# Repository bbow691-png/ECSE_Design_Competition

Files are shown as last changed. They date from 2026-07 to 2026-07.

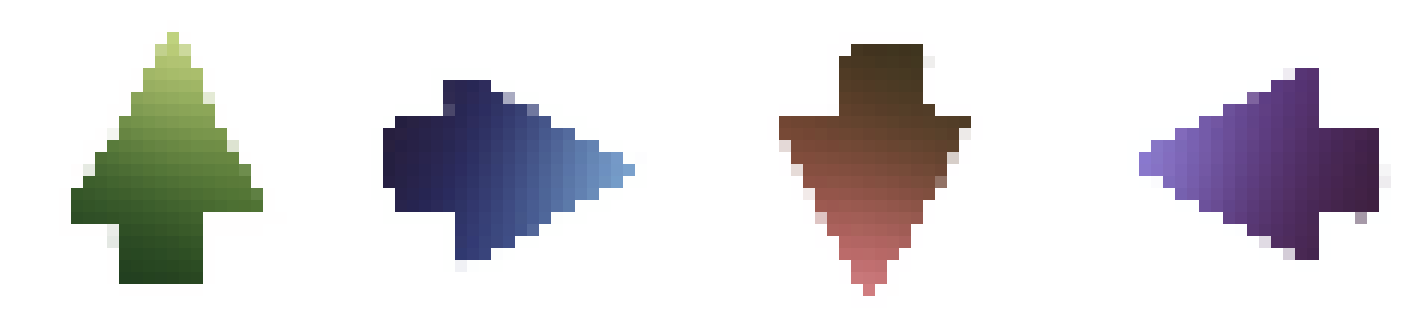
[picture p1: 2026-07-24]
godot/ecse-design/assets/images/Arrows.png

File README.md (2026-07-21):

🥁 ESP32 & Godot Rhythm Game

An open-source, hybrid rhythm game project combining custom ESP32 hardware (piezo drum pads over I2S) with a Godot 4.x game engine frontend. Hit your physical drum kit, stream analog transients via high-speed ADC sampling, and watch the notes fall in sync on your screen!

🛠️ Project Structure
├── src/                      # C++ PlatformIO firmware for the ESP32
├── godot/ecse-design/        # Godot 4.x Game Engine Project
│   ├── scenes/game_scene/    # Gameplay levels, lanes, and UI
│   ├── scripts/              # SongManager, PiezoInput, and Conductor logic
│   └── songs/                # JSON-based custom beatmaps & audio
└── run_instructions.md       # Detailed local setup guide
⚡ Part 1: Hardware Setup & ESP32 Firmware

The ESP32 uses built-in I2S ADC sampling at 20kHz to capture percussive transients from up to 4 piezo drum pads simultaneously, translating analog strikes into MIDI velocity data over USB Serial.

Prerequisites
VS Code with the PlatformIO extension installed
Flashing the ESP32
Open VS Code and use File > Open Folder to select the root folder containing your platformio.ini file.
Wait for PlatformIO to automatically download the required ESP32 toolchains and Arduino frameworks.
Plug your ESP32 into your computer via USB.
Click the Upload and Monitor button on the bottom status bar (or run PlatformIO: Upload and Monitor).
Tap your piezo drums — you should see live symbols popping up in the terminal.
Close the terminal and run stream_audio.py. This will result in meaningful text appearing in your terminal.
🎮 Part 2: Godot Game Engine Setup

The Godot frontend listens to incoming serial/network streams, handles lane input, and manages synchronized audio tracking alongside JSON-driven beatmaps.

Prerequisites
Godot Engine 4.x
Running the Project
Launch Godot Engine and click Import on the Project Manager screen.
Navigate into the repository folder, select the godot/ecse-design/ sub-folder, and select the project.godot file.
Once the editor loads your project, click the Play button (or press F5) in the top right corner.
🎵 Adding Custom Songs & Beatmaps

Songs are loaded dynamically via JSON files processed globally by the SongManager singleton.

To add a new song:

Create a folder inside res://songs/your_song_name/.
Add your audio file and a beatmap.json file structured like this:
json
{
  "title": "Your Song Title",
  "bpm": 120,
  "notes": [
    { "time": 2.0, "pad": 0 },
    { "time": 3.0, "pad": 1 },
    { "time": 4.0, "pad": 2 },
    { "time": 5.0, "pad": 3 }
  ]
}
Trigger the song in your scene script:
gdscript
SongManager.load_and_play_song("res://songs/your_song_name")
📄 License

This project is open-source and available for educational and personal use.

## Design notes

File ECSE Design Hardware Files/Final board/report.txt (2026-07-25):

Info: Processing symbol 'C1:Capacitor_SMD:C_0805_2012Metric_Pad1.18x1.45mm_HandSolder'.
Info: Processing symbol 'C2:Capacitor_THT:CP_Radial_D10.0mm_P5.00mm'.
Info: Processing symbol 'C3:Capacitor_SMD:C_0805_2012Metric_Pad1.18x1.45mm_HandSolder'.
Info: Processing symbol 'C4:Capacitor_SMD:C_0805_2012Metric'.
Info: Processing symbol 'C5:'.
Info: Processing symbol 'C6:Capacitor_SMD:C_0805_2012Metric_Pad1.18x1.45mm_HandSolder'.
Info: Processing symbol 'C7:Capacitor_SMD:C_0805_2012Metric_Pad1.18x1.45mm_HandSolder'.
Info: Processing symbol 'IC1:PAM8403:SOIC127P600X126-16N'.
Info: Processing symbol 'LEFT1:TerminalBlock:TerminalBlock_MaiXu_MX126-5.0-02P_1x02_P5.00mm'.
Info: Processing symbol 'R1:Resistor_SMD:R_0805_2012Metric_Pad1.20x1.40mm_HandSolder'.
Info: Processing symbol 'R2:Resistor_SMD:R_0805_2012Metric_Pad1.20x1.40mm_HandSolder'.
Info: Processing symbol 'R3:Resistor_SMD:R_0805_2012Metric_Pad1.20x1.40mm_HandSolder'.
Info: Processing symbol 'R4:Resistor_SMD:R_0805_2012Metric_Pad1.20x1.40mm_HandSolder'.
Info: Processing symbol 'RIGHT1:TerminalBlock:TerminalBlock_MaiXu_MX126-5.0-02P_1x02_P5.00mm'.
Info: Processing symbol 'U1:ESP32:MODULE_DEVKIT_V1_ESP32-WROOM-32'.
Info: Processing symbol 'U3:PCM5102A:PCM5102A'.
Info: Processing symbol 'UVD1:Package_TO_SOT_THT:TO-220-3_Vertical'.
Error: Cannot add C5 (no footprint assigned).

Info: Total warnings: 0, errors: 1.

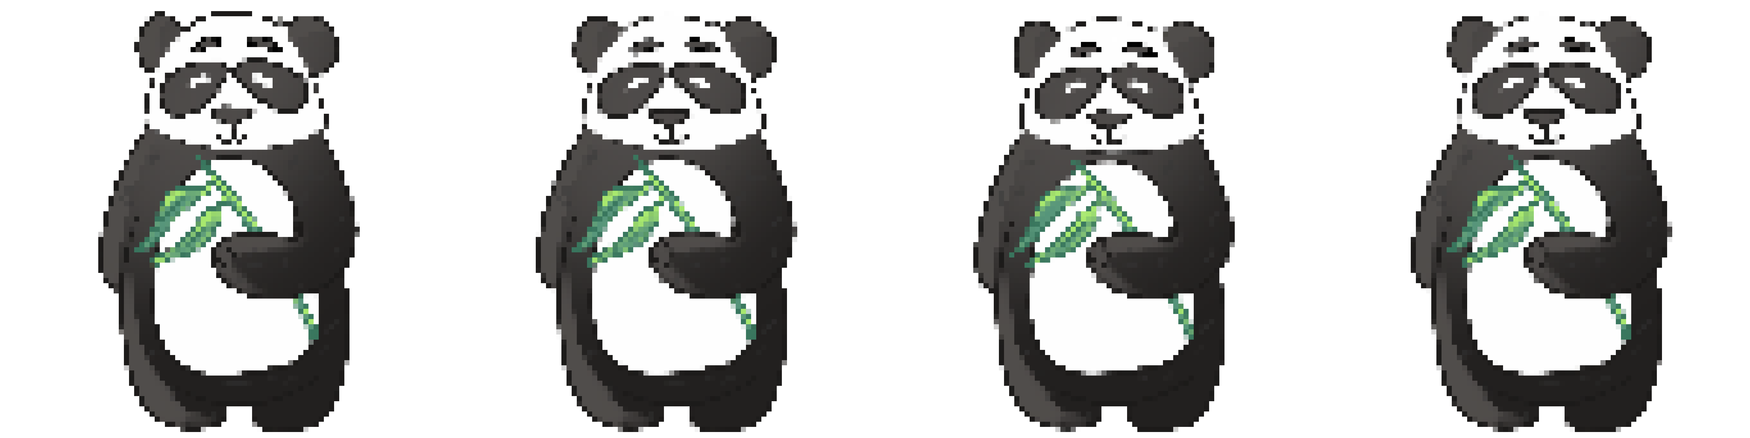
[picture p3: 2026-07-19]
godot/ecse-design/assets/Spritesheets/P_idle_spritesheet.png

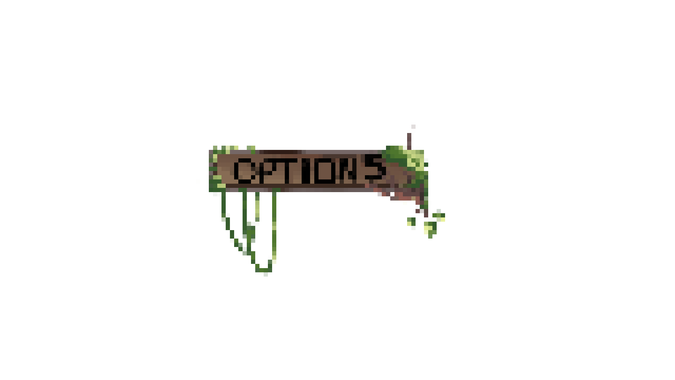
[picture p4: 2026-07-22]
godot/ecse-design/assets/Spritesheets/Options_button.png

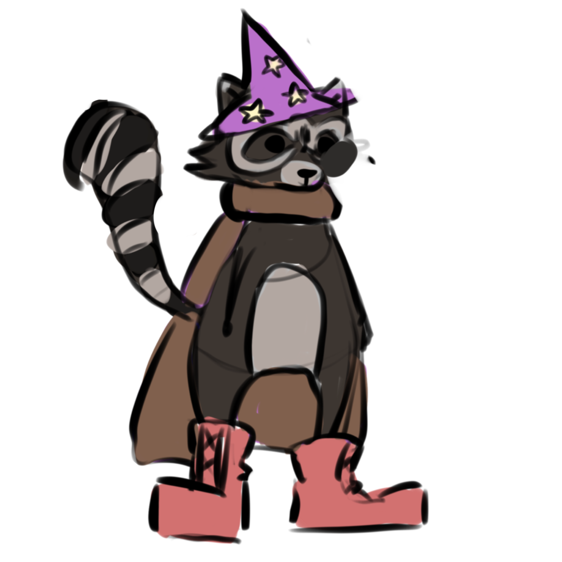
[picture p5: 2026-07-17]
godot/ecse-design/assets/images/Raccoon.png

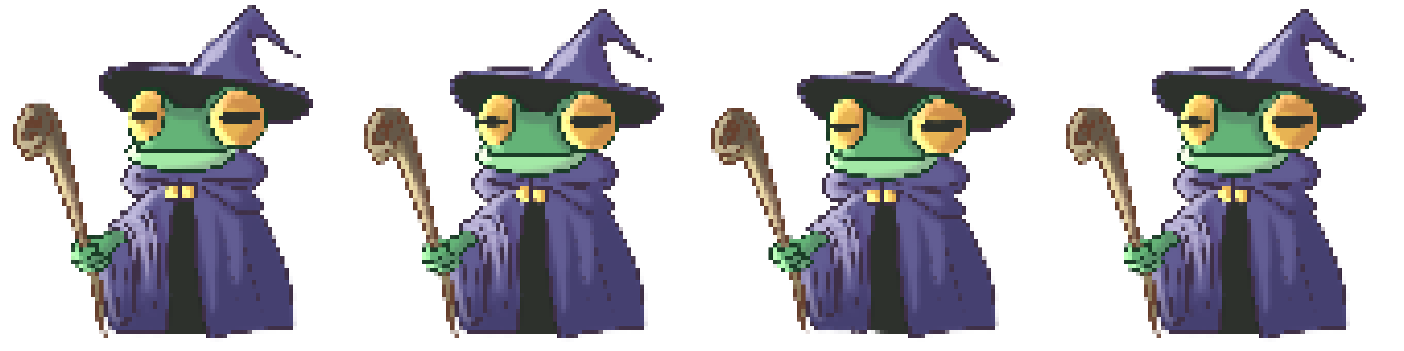
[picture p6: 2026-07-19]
godot/ecse-design/assets/Spritesheets/frog_idle_spritesheet.png

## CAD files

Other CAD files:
ECSE Design Hardware Files/Autodesk Files/Speaker Mount.f3d

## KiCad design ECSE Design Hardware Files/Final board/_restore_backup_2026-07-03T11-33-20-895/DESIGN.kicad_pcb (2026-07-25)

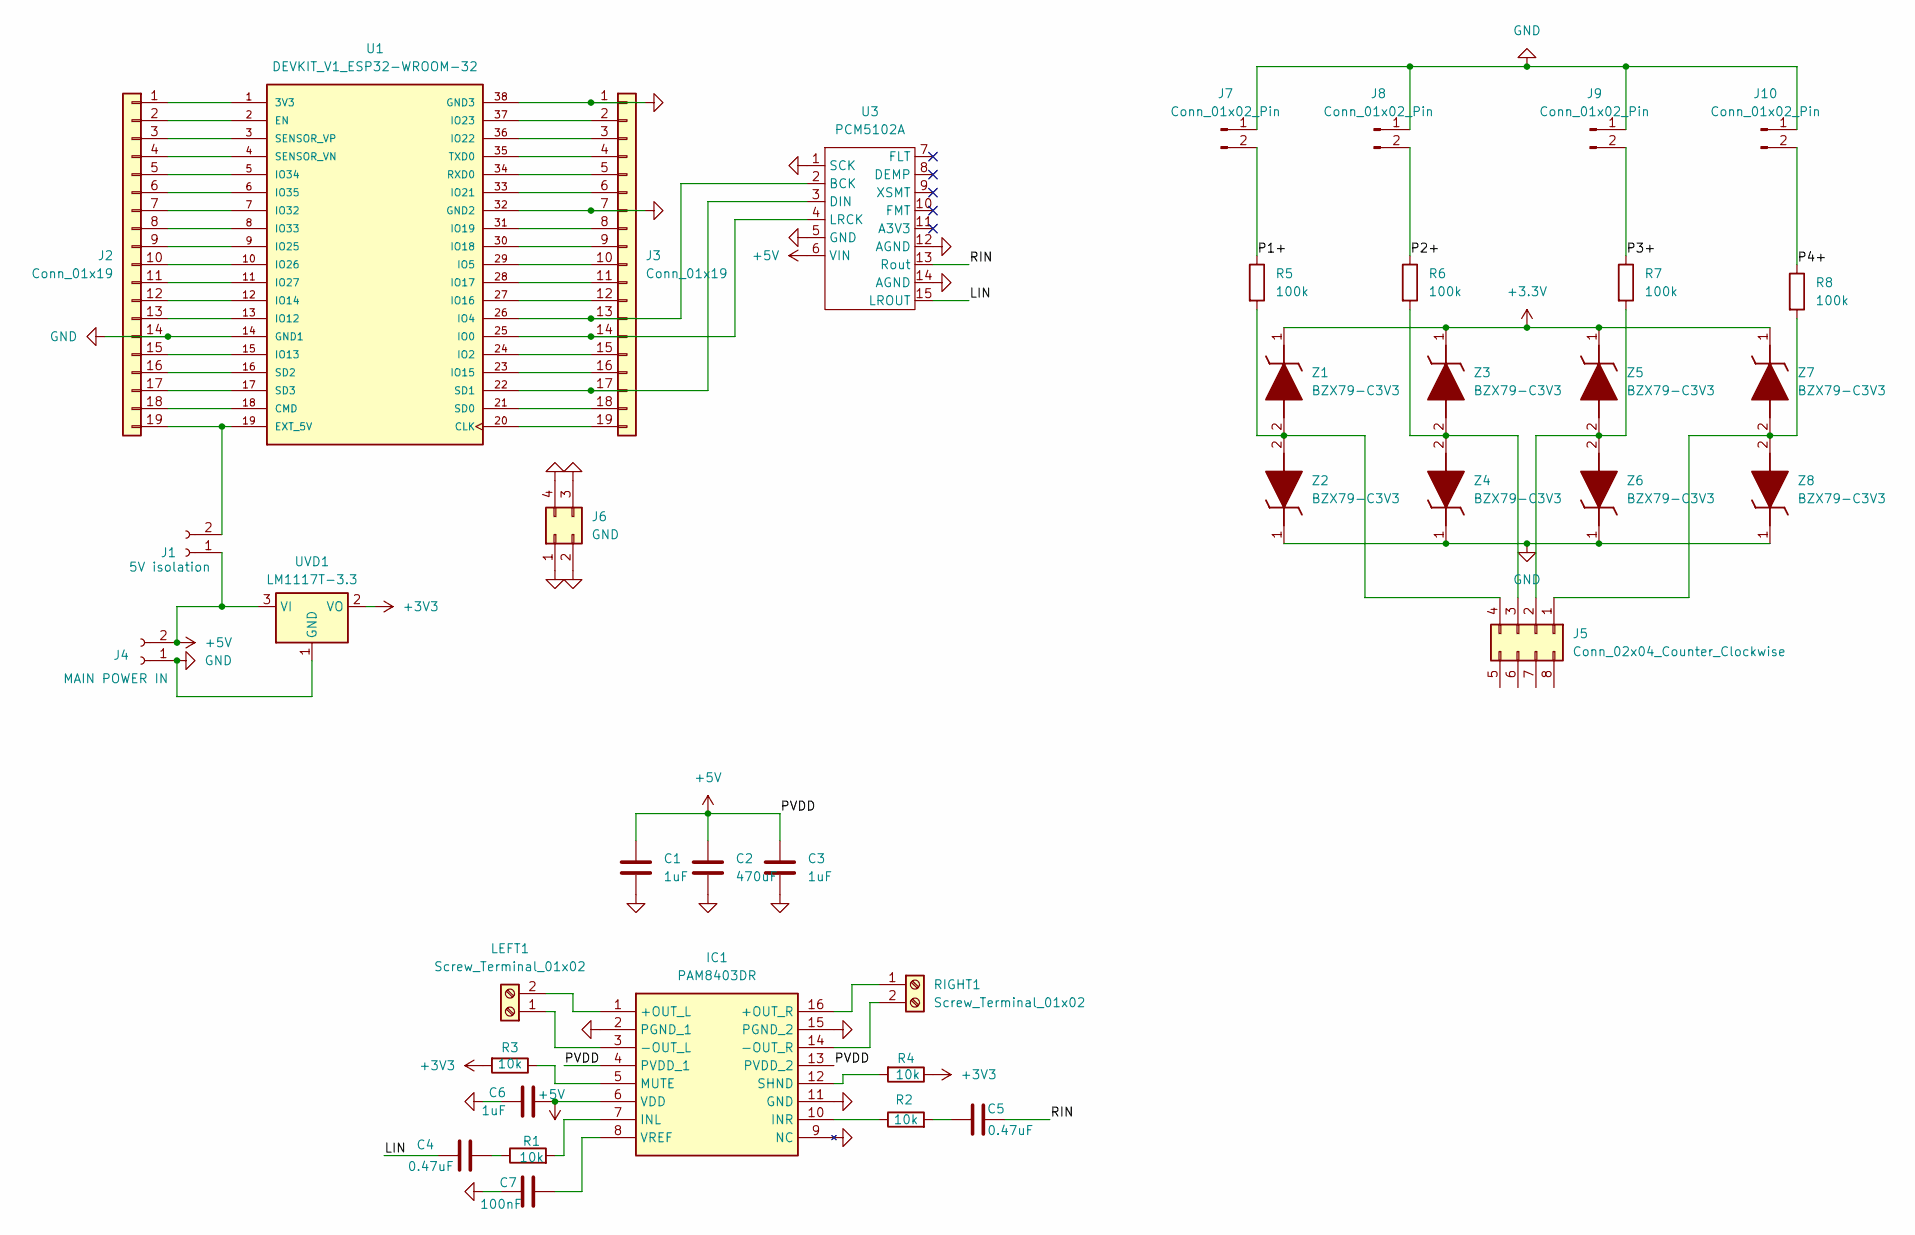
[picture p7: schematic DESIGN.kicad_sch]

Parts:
C1, C3, C6: 1uF; C_0805_2012Metric_Pad1.18x1.45mm_HandSolder
C2: 470uF; CP_Radial_D10.0mm_P5.00mm
C4: 0.47uF; C_0805_2012Metric_Pad1.18x1.45mm_HandSolder
C5: 0.47uF
C7: 100nF; C_0805_2012Metric_Pad1.18x1.45mm_HandSolder
IC1: PAM8403DR; SOIC127P600X126-16N; Manufacturer_Part_Number PAM8403DR; Mouser Part Number 621-PAM8403DR
J1: 5V isolation; PinHeader_1x02_P2.54mm_Vertical
J2, J3: Conn_01x19; PinHeader_1x19_P2.54mm_Vertical
J4: MAIN POWER IN; Power ECSE Design
J5: Conn_02x04_Counter_Clockwise; PinHeader_2x04_P2.54mm_Vertical
J6: GND
J7, J8, J9, J10: Conn_01x02_Pin; PinHeader_1x02_P2.54mm_Vertical
LEFT1: Screw_Terminal_01x02; TerminalBlock_MaiXu_MX126-5.0-02P_1x02_P5.00mm
R1, R2, R3, R4: 10k; R_0805_2012Metric_Pad1.20x1.40mm_HandSolder
R5, R6, R7, R8: 100k; R_0805_2012Metric_Pad1.20x1.40mm_HandSolder
RIGHT1: Screw_Terminal_01x02; TerminalBlock_MaiXu_MX126-5.0-02P_1x02_P5.00mm
U1: DEVKIT_V1_ESP32-WROOM-32; MODULE_DEVKIT_V1_ESP32-WROOM-32; PARTREV N/A
U3: PCM5102A
UVD1: LM1117T-3.3; TO-220-3_Vertical
Z1, Z2, Z3, Z4, Z5, Z6, Z7, Z8: BZX79-C3V3; DIOAD1165W56L425D185; Manufacturer_Part_Number BZX79-C3V3; Mouser Part Number N/A

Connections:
+3.3V: Z1.1 (K), Z3.1 (K), Z5.1 (K), Z7.1 (K)
+3V3: R3.2, R4.1, UVD1.2 (VO)
+5V: C1.1, C2.1, C3.1, C6.2, IC1.4 (PVDD_1), IC1.6 (VDD), IC1.13 (PVDD_2), J1.1, J4.2, U3.6 (VIN), UVD1.3 (VI)
/LIN: C4.1, U3.15 (LROUT)
/P1+: J7.2, R5.1
/P2+: J8.2, R6.1
/P3+: J9.2, R7.1
/P4+: J10.2, R8.1
/RIN: C5.2, U3.13 (Rout)
GND: C1.2, C2.2, C3.2, C6.1, C7.1, IC1.2 (PGND_1), IC1.9 (NC), IC1.11 (GND), IC1.15 (PGND_2), J2.14, J3.1, J3.7, J4.1, J6.1, J6.2, J6.3, J6.4, J7.1, J8.1, J9.1, J10.1, U1.14 (GND1), U1.32 (GND2), U1.38 (GND3), U3.1 (SCK), U3.5 (GND), U3.12 (AGND), U3.14 (AGND), UVD1.1 (GND), Z2.1 (K), Z4.1 (K), Z6.1 (K), Z8.1 (K)
unnamed: C4.2, R1.1
unnamed: C5.1, R2.2
unnamed: IC1.1 (+OUT_L), LEFT1.2
unnamed: IC1.16 (+OUT_R), RIGHT1.1
unnamed: IC1.3 (-OUT_L), LEFT1.1
unnamed: IC1.14 (-OUT_R), RIGHT1.2
unnamed: IC1.7 (INL), R1.2
unnamed: IC1.10 (INR), R2.1
unnamed: IC1.5 (MUTE), R3.1
unnamed: IC1.12 (SHND), R4.2
unnamed: C7.2, IC1.8 (VREF)
unnamed: J1.2, J2.19, U1.19 (EXT_5V)
unnamed: J2.1, U1.1 (3V3)
unnamed: J2.2, U1.2 (EN)
unnamed: J2.3, U1.3 (SENSOR_VP)
unnamed: J2.4, U1.4 (SENSOR_VN)
unnamed: J2.5, U1.5 (IO34)
unnamed: J2.6, U1.6 (IO35)
unnamed: J2.7, U1.7 (IO32)
unnamed: J2.8, U1.8 (IO33)
unnamed: J2.9, U1.9 (IO25)
unnamed: J2.10, U1.10 (IO26)
unnamed: J2.11, U1.11 (IO27)
unnamed: J2.12, U1.12 (IO14)
unnamed: J2.13, U1.13 (IO12)
unnamed: J2.15, U1.15 (IO13)
unnamed: J2.16, U1.16 (SD2)
unnamed: J2.17, U1.17 (SD3)
unnamed: J2.18, U1.18 (CMD)
unnamed: J3.2, U1.37 (IO23)
unnamed: J3.3, U1.36 (IO22)
unnamed: J3.4, U1.35 (TXD0)
unnamed: J3.5, U1.34 (RXD0)
unnamed: J3.6, U1.33 (IO21)
unnamed: J3.8, U1.31 (IO19)
unnamed: J3.9, U1.30 (IO18)
unnamed: J3.10, U1.29 (IO5)
unnamed: J3.11, U1.28 (IO17)
unnamed: J3.12, U1.27 (IO16)
unnamed: J3.13, U1.26 (IO4), U3.2 (BCK)
unnamed: J3.14, U1.25 (IO0), U3.4 (LRCK)
unnamed: J3.15, U1.24 (IO2)
unnamed: J3.16, U1.23 (IO15)
unnamed: J3.17, U1.22 (SD1), U3.3 (DIN)
unnamed: J3.18, U1.21 (SD0)
unnamed: J3.19, U1.20 (CLK)
unnamed 56: J5.1, R8.2, Z7.2 (A), Z8.2 (A); also elsewhere on the board
unnamed 57: J5.2, R7.2, Z5.2 (A), Z6.2 (A); also elsewhere on the board
unnamed 58: J5.3, R6.2, Z3.2 (A), Z4.2 (A); also elsewhere on the board
unnamed 59: J5.4, R5.2, Z1.2 (A), Z2.2 (A); also elsewhere on the board

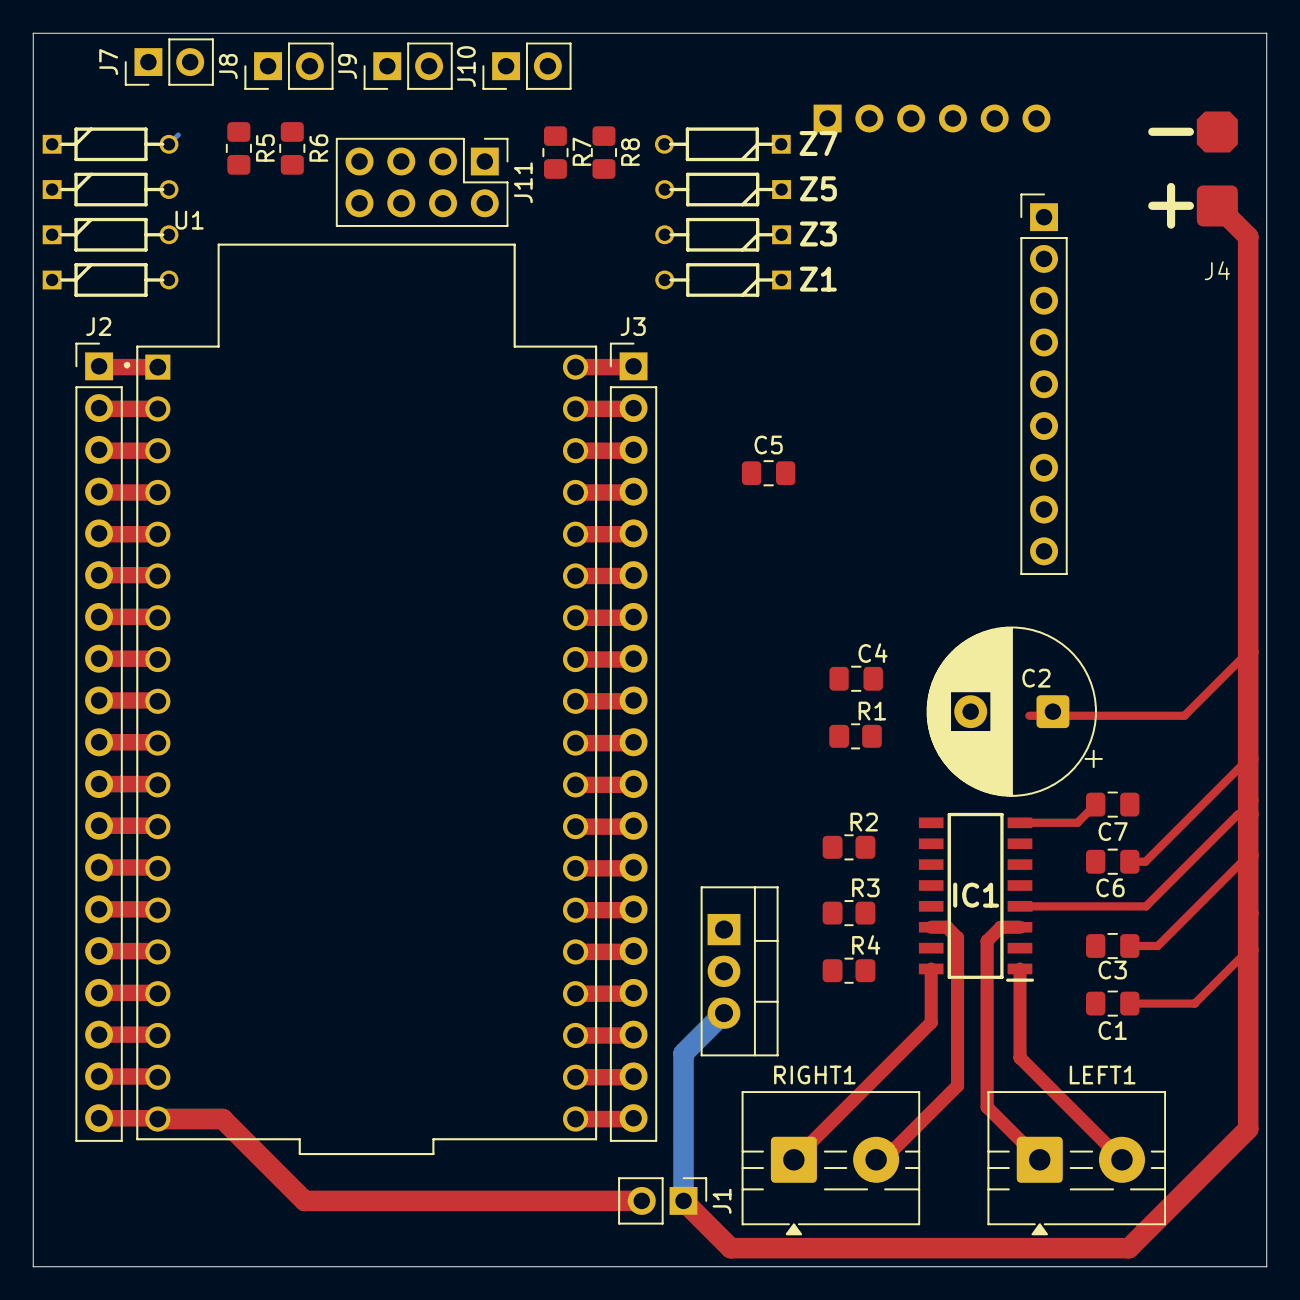
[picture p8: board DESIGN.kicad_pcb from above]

Board: 2 copper layers, 75.0 x 75.0 mm, 38 parts (0 on the bottom side), 60 nets.

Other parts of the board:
J11: Conn_02x04_Odd_Even; PinHeader_2x04_P2.54mm_Vertical

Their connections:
unnamed 56: J11.1; also elsewhere on the board
unnamed 57: J11.3; also elsewhere on the board
unnamed 58: J11.5; also elsewhere on the board
unnamed 59: J11.7; also elsewhere on the board

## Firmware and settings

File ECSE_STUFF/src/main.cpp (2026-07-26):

#include <Arduino.h>
#include <driver/i2s.h>

//------------------------------Pin Definitions--------------------------------//
#define I2S_BCK_PIN   26    //Bit clock pin
#define I2S_LRCK_PIN  25    //Left/right clock pin
#define I2S_DOUT_PIN  23    //Data out pin

//Piezo input pins (input only on 34/35, input/output on 32/33)
#define PIEZO_1  34
#define PIEZO_2  35
#define PIEZO_3  32
#define PIEZO_4  33

//------------------------------Audio Config-----------------------------------//
#define SAMPLE_RATE   22050     //Sample rate (Hz)
#define I2S_PORT      I2S_NUM_0 //I2S peripheral port
#define DMA_BUF_COUNT 16        //Direct memory access buffer count
#define DMA_BUF_LEN   128       //Direct memory access buffer length

//------------------------------Serial Config-----------------------------------//
#define SERIAL_BAUD    921600
//Default HardwareSerial RX buffer is only 256B. PC sends ~1KB audio chunks
//every ~11ms, so without a bigger buffer bytes get dropped between loop()
//passes long before we ever get a chance to read them.
#define SERIAL_RX_BUF  4096
#define AUDIO_CHUNK    512      //Max bytes pulled from Serial per loop pass

//------------------------------Piezo Config-----------------------------------//
#define STRIKE_THRESHOLD    500  //ADC value to trigger a hit (0-4095)
#define DEBOUNCE_MS         150   //Per-channel: minimum time between strikes on the same pad (ms)
#define HOLD_MS             20   //Per-channel: how long to hold triggered state (ms)
//A real strike's vibration reaches neighbouring piezos within ~1ms and can
//cross their threshold too. Once any channel fires, ignore ALL channels for
//this long so one physical hit can't be reported as hits on multiple pads.
#define CROSSTALK_MASK_MS   15  //Time debounce before A strike can take place again on the same channel

//Struct to track state of each piezo channel
struct PiezoChannel {
    uint8_t pin;                //GPIO pin number
    unsigned long last_strike;  //Timestamp of last strike (ms)
    bool triggered;             //Currently in triggered state
};

//Initialise all four channels
PiezoChannel channels[] = {
    { PIEZO_1, 0, false },
    { PIEZO_2, 0, false },
    { PIEZO_3, 0, false },
    { PIEZO_4, 0, false }
};

const int NUM_CHANNELS = 4;
static unsigned long last_hit_ms = 0;  //Across all channels, for the crosstalk mask

//------------------------------I2S Configuration---------------------------------//
void i2s_init() {
    i2s_config_t cfg = {
        .mode                 = (i2s_mode_t)(I2S_MODE_MASTER | I2S_MODE_TX), //Master transmit only
        .sample_rate          = SAMPLE_RATE,
        .bits_per_sample      = I2S_BITS_PER_SAMPLE_16BIT,                   //16 bit stereo
        .channel_format       = I2S_CHANNEL_FMT_RIGHT_LEFT,                  //Stereo L+R
        .communication_format = I2S_COMM_FORMAT_STAND_I2S,                   //Standard I2S framing
        .intr_alloc_flags     = ESP_INTR_FLAG_LEVEL1,                        //Interrupt priority
        .dma_buf_count        = DMA_BUF_COUNT,
        .dma_buf_len          = DMA_BUF_LEN,
        .use_apll             = true,           //Use audio PLL for lower jitter
        .tx_desc_auto_clear   = true             //Clear DMA on underrun
    };

    i2s_pin_config_t pins = {
        .bck_io_num   = I2S_BCK_PIN,
        .ws_io_num    = I2S_LRCK_PIN,
        .data_out_num = I2S_DOUT_PIN,
        .data_in_num  = I2S_PIN_NO_CHANGE      //No input needed
    };

    //Install driver, configure pins and clear DMA buffer
    i2s_driver_install(I2S_PORT, &cfg, 0, NULL);
    i2s_set_pin(I2S_PORT, &pins);
    i2s_zero_dma_buffer(I2S_PORT);
}

//------------------------------Piezo Strike Detection (Core 0 task)-----------//
//Runs as its own FreeRTOS task pinned to Core 0, entirely separate from the
//Core 1 loop() that pumps audio - so piezo polling and HIT reporting can
//never stall audio playback, and vice versa. WiFi is gone (audio moved to
//serial), so Core 0 has nothing else meaningful running on it.
void piezo_task(void* pvParameters) {
    for (;;) {
        unsigned long now = millis();
        bool masked = (now - last_hit_ms) < CROSSTALK_MASK_MS;

        for (int i = 0; i < NUM_CHANNELS; i++) {
            PiezoChannel& ch = channels[i];

            //Read ADC value (0-4095 for 12-bit)
            int raw = analogRead(ch.pin);

            //Detect new strike: above threshold, this channel isn't already
            //mid-strike, its own debounce has elapsed, and no other channel
            //has claimed this hit already (crosstalk mask).
            if (!masked && raw > STRIKE_THRESHOLD && !ch.triggered &&
                (now - ch.last_strike) > DEBOUNCE_MS) {

                ch.triggered = true;
                ch.last_strike = now;
                last_hit_ms = now;
                masked = true;  //claim this hit for the rest of this pass too

                //Hit event over serial to the PC bridge. Format: HIT:channel
                Serial.print("HIT:");
                Serial.println(i + 1);
            }

            //Reset triggered state after hold period
            if (ch.triggered && (now - ch.last_strike) > HOLD_MS) {
                ch.triggered = false;
            }
        }

        vTaskDelay(1);  //~1kHz sampling per channel; yields so Core 0's idle task/watchdog stays happy
    }
}

//------------------------------Serial Audio Ingestion--------------------------//
//Pulls whatever bytes are already sitting in the RX buffer without blocking,
//so loop() stays responsive even when the link is idle. Only whole 16-bit
//stereo frames (4 bytes: L16+R16) are handed to I2S so a read landing
//mid-frame doesn't leave the L/R channels permanently swapped.
static uint8_t audio_buf[AUDIO_CHUNK];
static size_t audio_buf_len = 0;

void pump_audio() {
    int avail = Serial.available();
    if (avail <= 0) return;

    size_t space = sizeof(audio_buf) - audio_buf_len;
    size_t to_read = min((size_t)avail, space);
    if (to_read > 0) {
        audio_buf_len += Serial.readBytes(audio_buf + audio_buf_len, to_read);
    }

    size_t frame_bytes = audio_buf_len - (audio_buf_len % 4);
    if (frame_bytes == 0) return;

    size_t written = 0;
    //ticks_to_wait = 0: never block the loop waiting on the DMA queue.
    //The DMA buffer holds ~90ms of audio so this only matters if playback
    //is already badly behind, in which case a momentary channel swap is an
    //acceptable trade-off against freezing piezo detection.
    i2s_write(I2S_PORT, audio_buf, frame_bytes, &written, 0);

    size_t remainder = audio_buf_len - written;
    if (remainder > 0) memmove(audio_buf, audio_buf + written, remainder);
    audio_buf_len = remainder;
}

//------------------------------Setup and Main Loop----------------------------//
void setup() {
    Serial.setRxBufferSize(SERIAL_RX_BUF);
    Serial.begin(SERIAL_BAUD);
    Serial.println("Drum Cabinet starting...");

    //GPIO 32/33 need explicit pinMode, 34/35 are input only by default
    pinMode(PIEZO_3, INPUT);
    pinMode(PIEZO_4, INPUT);

    i2s_init();

    //Pin piezo polling to Core 0 so it runs fully in parallel with the audio
    //pump on Core 1 (loop()) instead of competing with it for loop time.
    xTaskCreatePinnedToCore(piezo_task, "piezo_task", 4096, NULL, 1, NULL, 0);

    Serial.println("Ready");
}

void loop() {
    pump_audio();
}

//-----------------------------------------------------------------------------//

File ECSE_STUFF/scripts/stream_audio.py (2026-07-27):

import serial
import soundcard as sc
import numpy as np
import socket
import re
import threading
import time

PORT = "COM3" # MAKE SURE TO MATCH THIS TO THE PORT YOUR ESP IS CONNECTED TO
BAUD = 921600
SAMPLE_RATE = 22050
CHUNK_SIZE = 256

# UDP config (piezo hits -> Godot). Matches godot/ecse-design/scripts/piezo_input.gd's contract.
UDP_IP = "127.0.0.1"
UDP_PORT = 5005

# Match lines like: HIT:1 (channel only - the game doesn't use hit velocity)
HIT_PATTERN = re.compile(rb'HIT:(\d+)')

def read_hits(ser, sock, stop_event):
    buf = bytearray()
    while not stop_event.is_set():
        try:
            # Safely check if port is open before reading
            if not ser.is_open:
                break

            in_wait = ser.in_waiting if ser.is_open else 0
            chunk = ser.read(max(in_wait, 1))
        except Exception:
            break

        if not chunk:
            continue

        buf.extend(chunk)
        while b"\n" in buf:
            line, _, rest = buf.partition(b"\n")
            buf = bytearray(rest)
            match = HIT_PATTERN.search(line)
            if match:
                channel = match.group(1).decode()
                sock.sendto(channel.encode(), (UDP_IP, UDP_PORT))
                print(f"Hit: Piezo {channel}")


def stream_loopback(ser, stop_event):
    speaker = sc.default_speaker()
    mic = sc.get_microphone(speaker.id, include_loopback=True)
    print(f"Capturing from: {speaker.name}")
    print(f"Sample rate: {SAMPLE_RATE}Hz | Port: {ser.port}")

    with mic.recorder(samplerate=SAMPLE_RATE, channels=2) as recorder:
        while not stop_event.is_set():
            data = recorder.record(numframes=CHUNK_SIZE)
            data_int16 = (data * 32767).astype(np.int16)
            ser.write(data_int16.tobytes())


def main():
    sock = socket.socket(socket.AF_INET, socket.SOCK_DGRAM)
    stop_event = threading.Event()
    ser = None
    reader_thread = None

    try:
        ser = serial.Serial(PORT, BAUD, timeout=0.1)
        time.sleep(2)

        reader_thread = threading.Thread(
            target=read_hits, args=(ser, sock, stop_event), daemon=True
        )
        reader_thread.start()

        print("Listening for piezo hits — press Ctrl+C to stop")
        # stream_loopback(ser, stop_event)

        # Keep the main thread alive indefinitely while read_hits() runs in
        # the background. Without this, main() falls straight through to
        # `finally` right after starting the thread (since stream_loopback
        # is disabled) and the program shuts down almost immediately instead
        # of staying up to listen for piezo hits.
        while not stop_event.is_set():
            time.sleep(0.5)

    finally:
        print("\nCleaning up resources...")
        # 1. Signal thread to exit loops
        stop_event.set()

        # 2. Give the thread time to release the serial port
        if reader_thread and reader_thread.is_alive():
            reader_thread.join(timeout=1.0)

        # 3. Explicitly close port and socket safely
        if ser and ser.is_open:
            ser.close()
            print("Serial port closed successfully.")

        sock.close()


if __name__ == "__main__":
    try:
        main()
    except KeyboardInterrupt:
        print("Streaming stopped by user.")
    except serial.SerialException as e:
        print(f"Serial error: {e}")

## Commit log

2026-07-18 Rework ESP32<->PC link for full-duplex serial audio+input, wire hits into Godot
    - ESP32 firmware: replace WiFi/UDP audio with non-blocking serial audio
    ingestion (larger RX buffer, frame-aligned) so audio-in and piezo HIT-out
    share one USB serial link without starving piezo polling.
    - stream_audio.py: merge audio streaming and hit-forwarding into a single
    process (writer + reader thread on one serial handle), since two
    processes can't hold the same COM port open; fix hardcoded COM5->COM3;
    harden reader thread to exit quietly if the port closes underneath it.
    - Add godot/ecse-design/scripts/piezo_input.gd: autoload that listens for
    forwarded hit UDP packets and injects them as rea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
    [main.cpp, stream_audio.py]
2026-07-20 Fix piezo crosstalk/audio clipping, drop unused hit velocity, resolve merge conflict
    - ESP32 firmware: move piezo polling+hit detection to its own FreeRTOS task
    pinned to Core 0 (idle since WiFi audio was removed), fully decoupled from
    the Core 1 loop() that pumps audio - so piezo work can no longer stall
    audio playback.
    - Add a global crosstalk mask: one physical strike reaches neighbouring
    piezos within ~1ms and can cross their threshold too; once any channel
    fires, all channels are briefly ignored so one hit can't be reported as
    hits on multiple pads.
    - Drop hit velocity end-to-end (firmware, stream_audio.py, piezo_input.gd)
    since the game only needs hit recognition - also s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
    [main.cpp, stream_audio.py]
2026-07-25 Adding new supporting hardware Files.
    [DESIGN-B_Cu.gbr, DESIGN-B_Mask.gbr, DESIGN-B_Paste.gbr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]
2026-07-26 fixed debounce timings after play testing
    [main.cpp]
2026-07-26 Finished scene 2 and scene 1. added map marker to track which levvel is selected
